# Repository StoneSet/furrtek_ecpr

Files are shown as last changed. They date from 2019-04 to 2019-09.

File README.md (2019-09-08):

# EPAR EMITTER HACK

## The Eagle project of the epar project + and modified firmware

**(c) Found the entire project here : http://furrtek.free.fr/?a=epar**

## For futher

As we know, only 350 cities (minimum), have been equipped with this system, (which makes 10% of the total cities in France in 2014). To have this famous cities code which is coded on 8 bits (so 255 possibilities), it is necessary to scan the frequencies 31MHz to 32MHz, which is tedious, this repo proposes to you a "brut-force", the program has been modified so that the 255 possibilities are tested. Once you have the code you can directly inform it in the remote control, it will go faster. This is just the theory, I have not tried it yet, but I would update this readme as soon as I have some pretty big breakthroughs.

## Included:

- All needed files to modify the project
- BOM (see in /pcb/)
- 🚧 Modified firmware (see in /firmware/) in WIP

## To use it :

1. Buy the pcb then solder every composants.
2. Flash the Atmega8 with *eparremote.hex* with these fuses :

- Low: *0xE4*, High: *0xD9*
## Some img's :

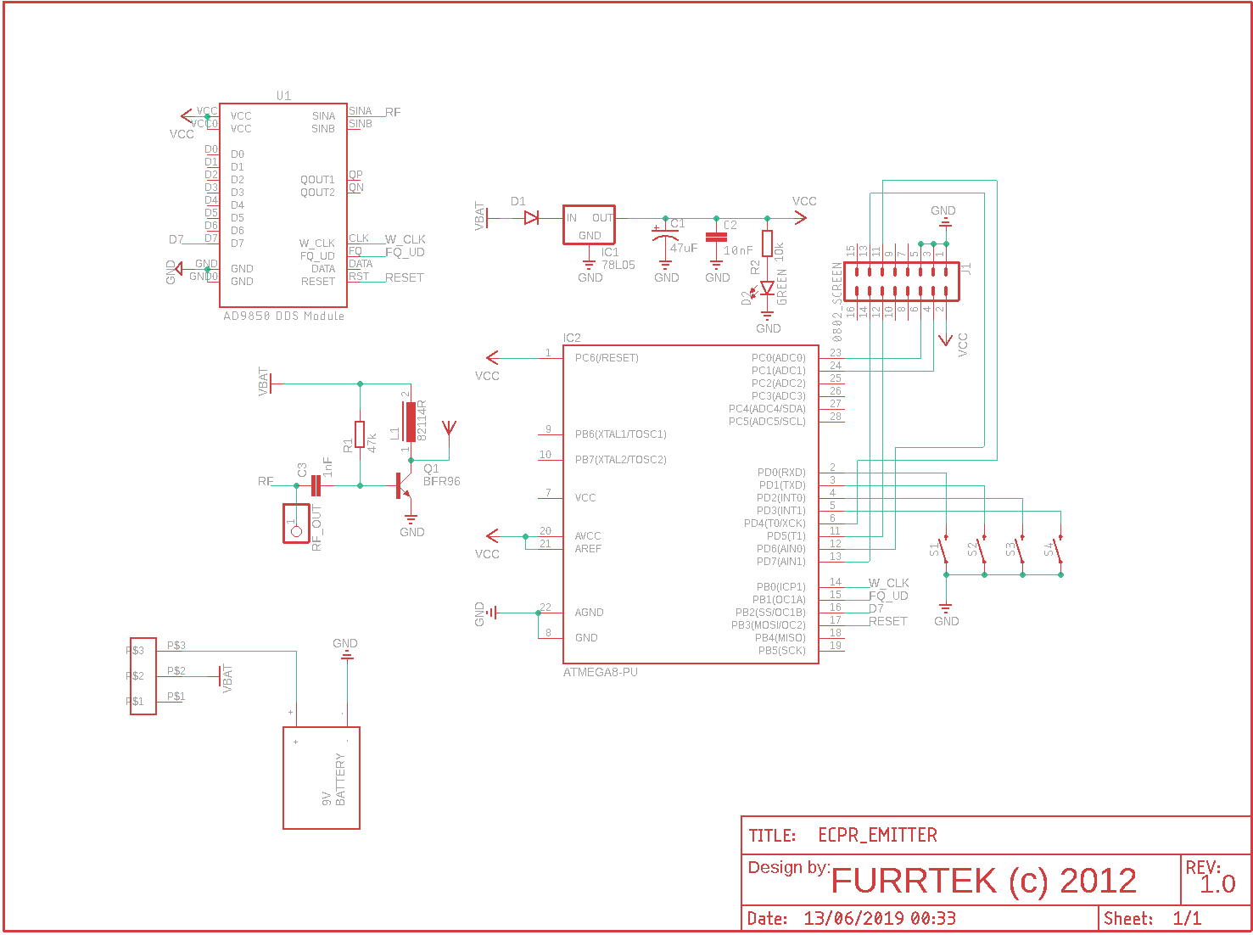
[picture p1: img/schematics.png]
schematic
remote 

gif_sdr#

### To dot it, you will need :

| Components | list |
|--|--|
| x1 Atmega8 | x1 78L05 regulator |
| x1 10k potentiometer | x4 12mm switch |
| x1 0802 screen | x1 AD9850 |
| x1 10k resistor | x1 47uF capacitor |
| x1 100uH coil | x1 Green led |
| x1 1nF capacitor | x1 10nF capacitor |
| x1 BFR96 | x1 47k resistor |
| x1 SPDT switch | x1 FM antenna |
| x1 9v clip | x1 1N4001 diode |

Tested, it will work perfectly !

#

(c) @furrtek & @StoneSet & @lefuturiste - http://furrtek.free.fr/?a=esl - http://stoneset.github.io/ (2019)

plz do not steal, i'm not the owner of this project, i'm only the owner of this pcb. Have fun !

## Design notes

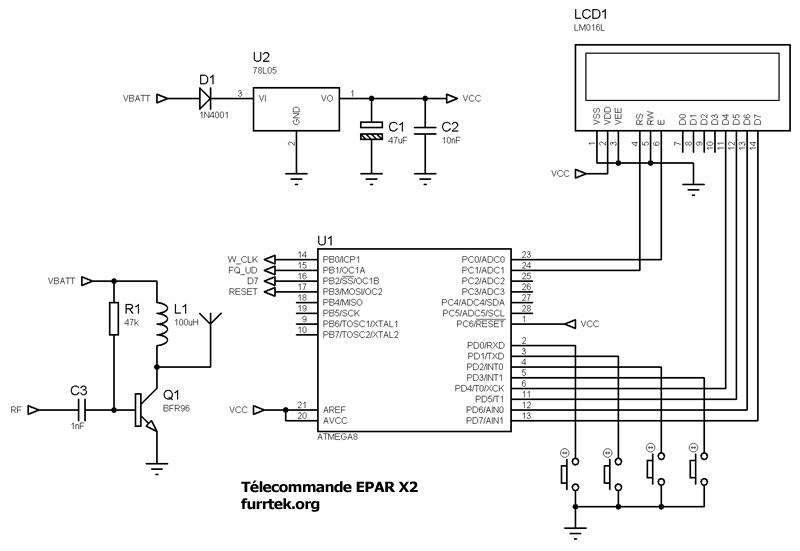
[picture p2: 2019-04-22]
img/schematics_furrtek.png

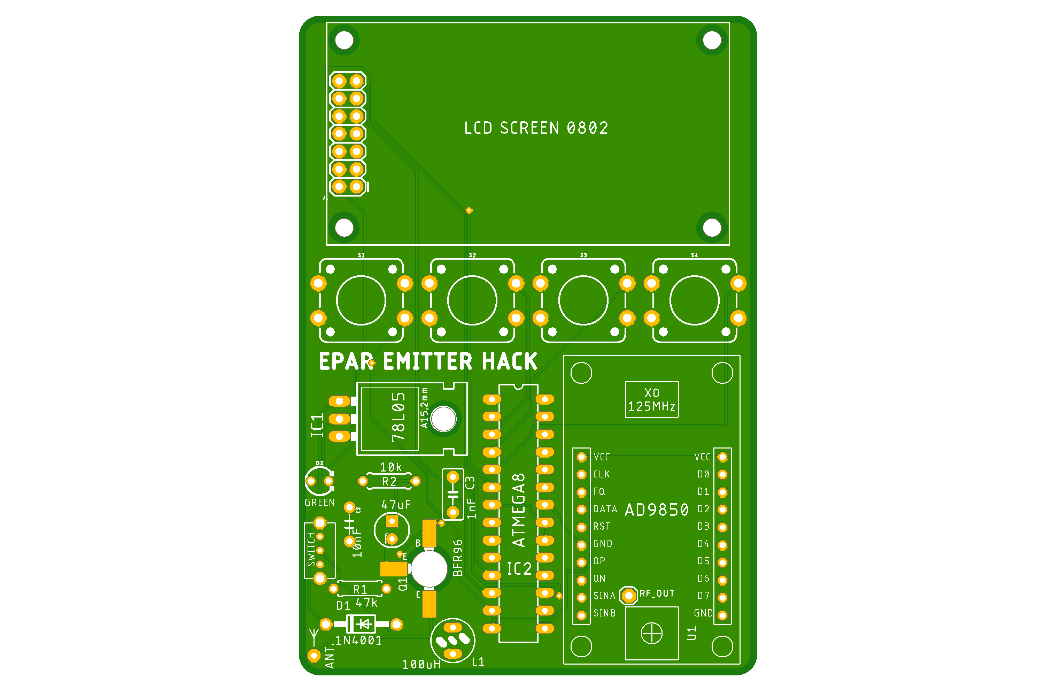
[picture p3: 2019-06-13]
img/board_top.png

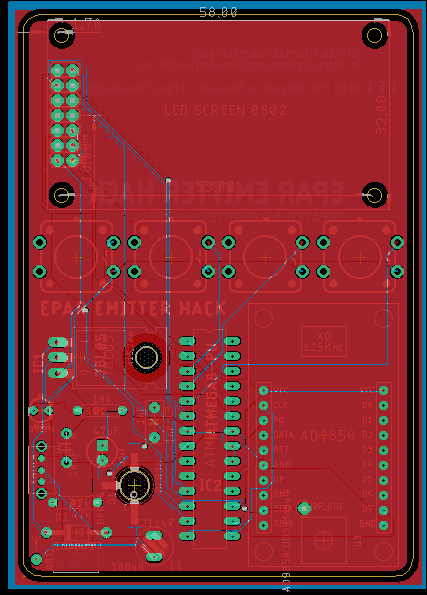
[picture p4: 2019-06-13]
img/board.png

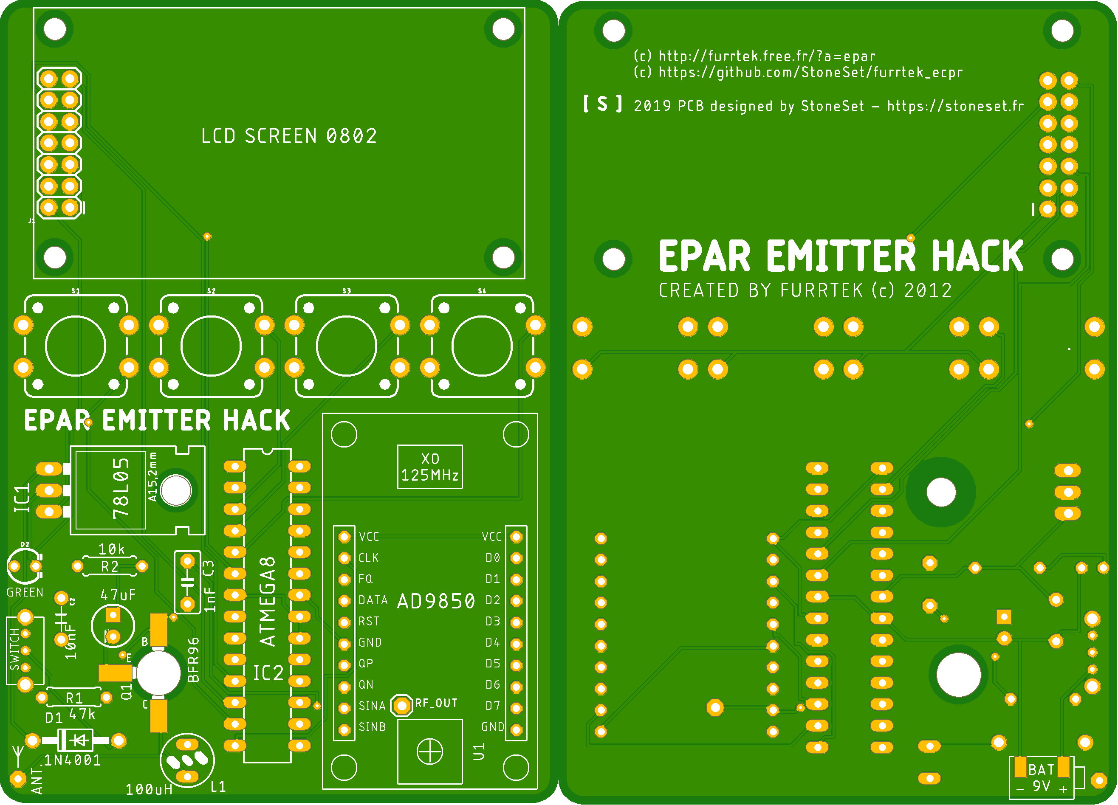
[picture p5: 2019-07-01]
img/top_bot.png

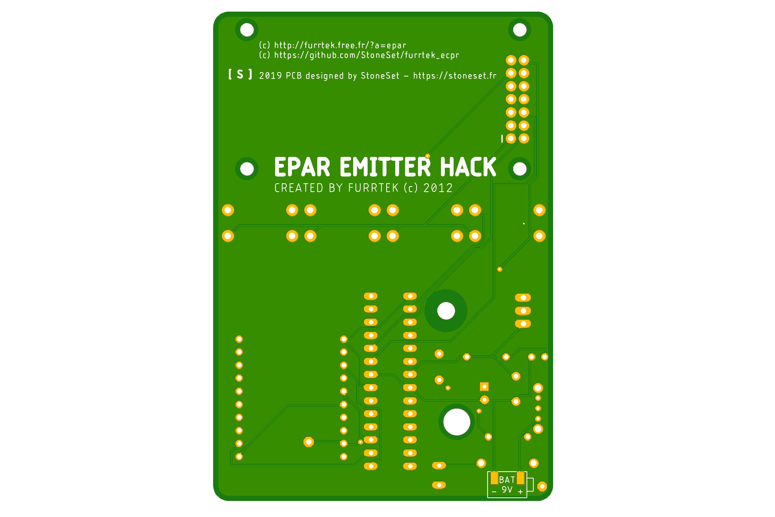
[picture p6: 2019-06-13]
img/board_bot.png

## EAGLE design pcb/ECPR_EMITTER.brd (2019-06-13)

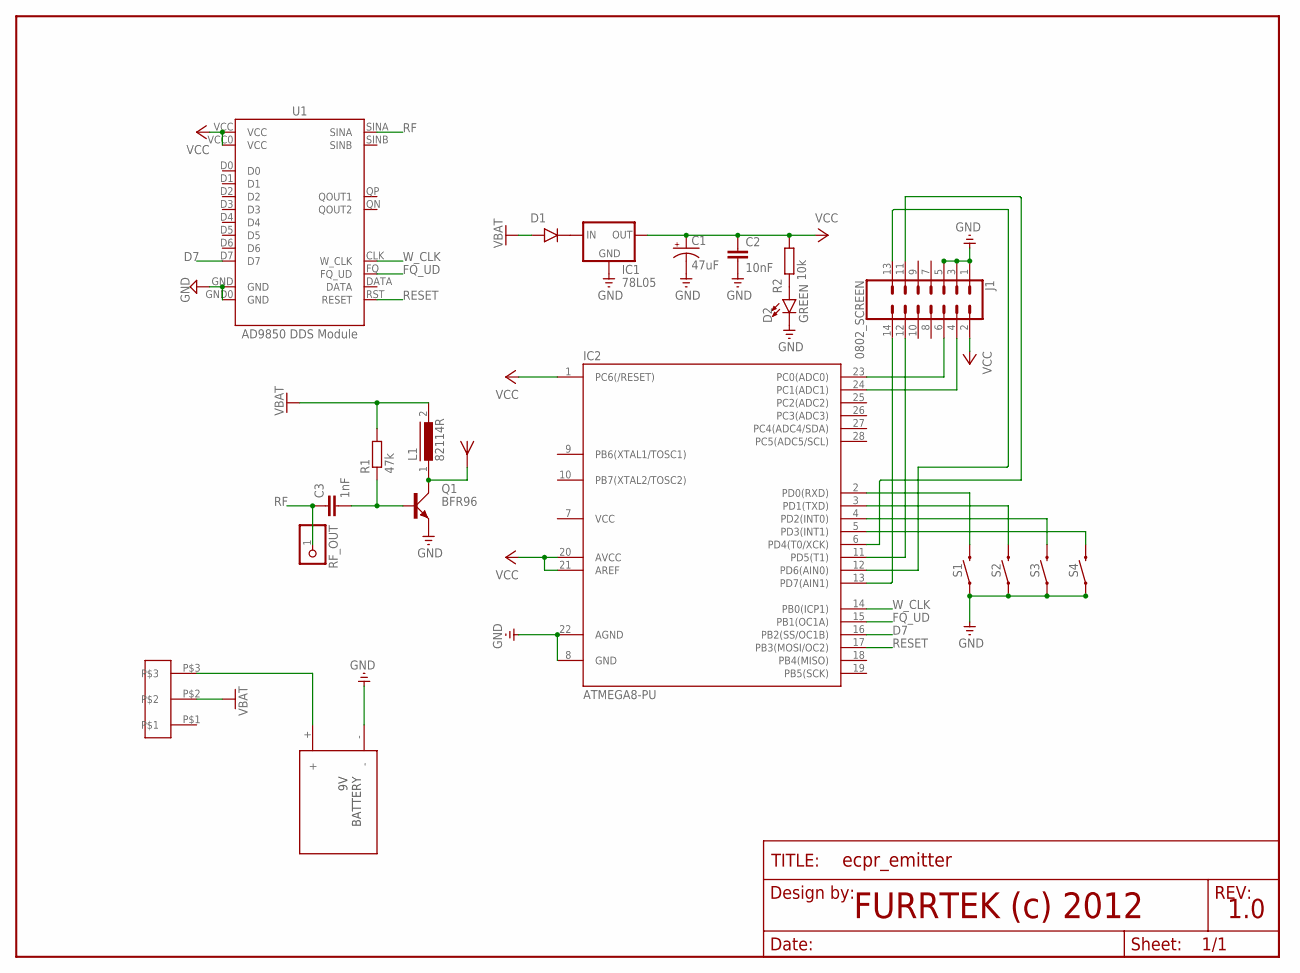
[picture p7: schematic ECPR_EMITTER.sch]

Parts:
C1: 47uF; CPOL-RADIAL-10UF-25V
C2: 10nF; CAP-PTH-10MM
C3: 1nF; C5B3
D1: 1N4001; DO41-10
D2: GREEN; LED_3MM-NS
FRAME1: FRAME-LETTERNO_PACKAGE; DUMMY
IC1: 78L05; 78XXL
IC2: ATMEGA8-PU; DIL28-3
J1: 0802_SCREEN; 2X8
L1: 82114R
Q1: BFR96; SOT37
R1: 47k; 0207/7
R2: 10k; 0207/7
RF_OUT: PINHD-1X1; 1X01
S1, S2, S3, S4: MOMENTARY-SWITCH-SPST-PTH-12MM; TACTILE_SWITCH_PTH_12MM
U1: AD9850 DDS Module; DDS_AD9850
U$1: ANT.; ANTENNA
U$2: PACKAGESWITCH; SLIDESWITCH
U$3: BAT

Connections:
D7: IC2.16 (PB2(SS/OC1B)), U1.D7
FQ_UD: IC2.15 (PB1(OC1A)), U1.FQ (FQ_UD)
GND: C1.2 (-), C2.2, D2.K (C), IC1.GND, IC2.8 (GND), IC2.22 (AGND), J1.1, J1.3, J1.5, Q1.2 (E), S1.1, S2.1, S3.1, S4.1, U1.GND, U1.GND0 (GND), U$3.-
unnamed: D1.C (CATHODE), IC1.IN
unnamed: C3.2, Q1.3 (B), R1.1
unnamed: IC2.2 (PD0(RXD)), S1.3 (2)
unnamed: IC2.3 (PD1(TXD)), S2.3 (2)
unnamed: IC2.4 (PD2(INT0)), S3.3 (2)
unnamed: IC2.5 (PD3(INT1)), S4.3 (2)
unnamed: L1.1, Q1.1 (C), U$1.ANT
unnamed: IC2.24 (PC1(ADC1)), J1.4
unnamed: IC2.23 (PC0(ADC0)), J1.6
unnamed: IC2.13 (PD7(AIN1)), J1.14
unnamed: IC2.11 (PD5(T1)), J1.12
unnamed: U$2.P$3, U$3.+
unnamed: IC2.12 (PD6(AIN0)), J1.13
unnamed: IC2.6 (PD4(T0/XCK)), J1.11
unnamed: D2.A, R2.1
RESET: IC2.17 (PB3(MOSI/OC2)), U1.RST (RESET)
RF: C3.1, RF_OUT.1, U1.SINA
VBAT: D1.A (ANODE), L1.2, R1.2, U$2.P$2
VCC: C1.1 (+), C2.1, IC1.OUT, IC2.1 (PC6(/RESET)), IC2.7 (VCC), IC2.20 (AVCC), IC2.21 (AREF), J1.2, R2.2, U1.VCC, U1.VCC0 (VCC)
W_CLK: IC2.14 (PB0(ICP1)), U1.CLK (W_CLK)

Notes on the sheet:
FURRTEK (c) 2012
1.0

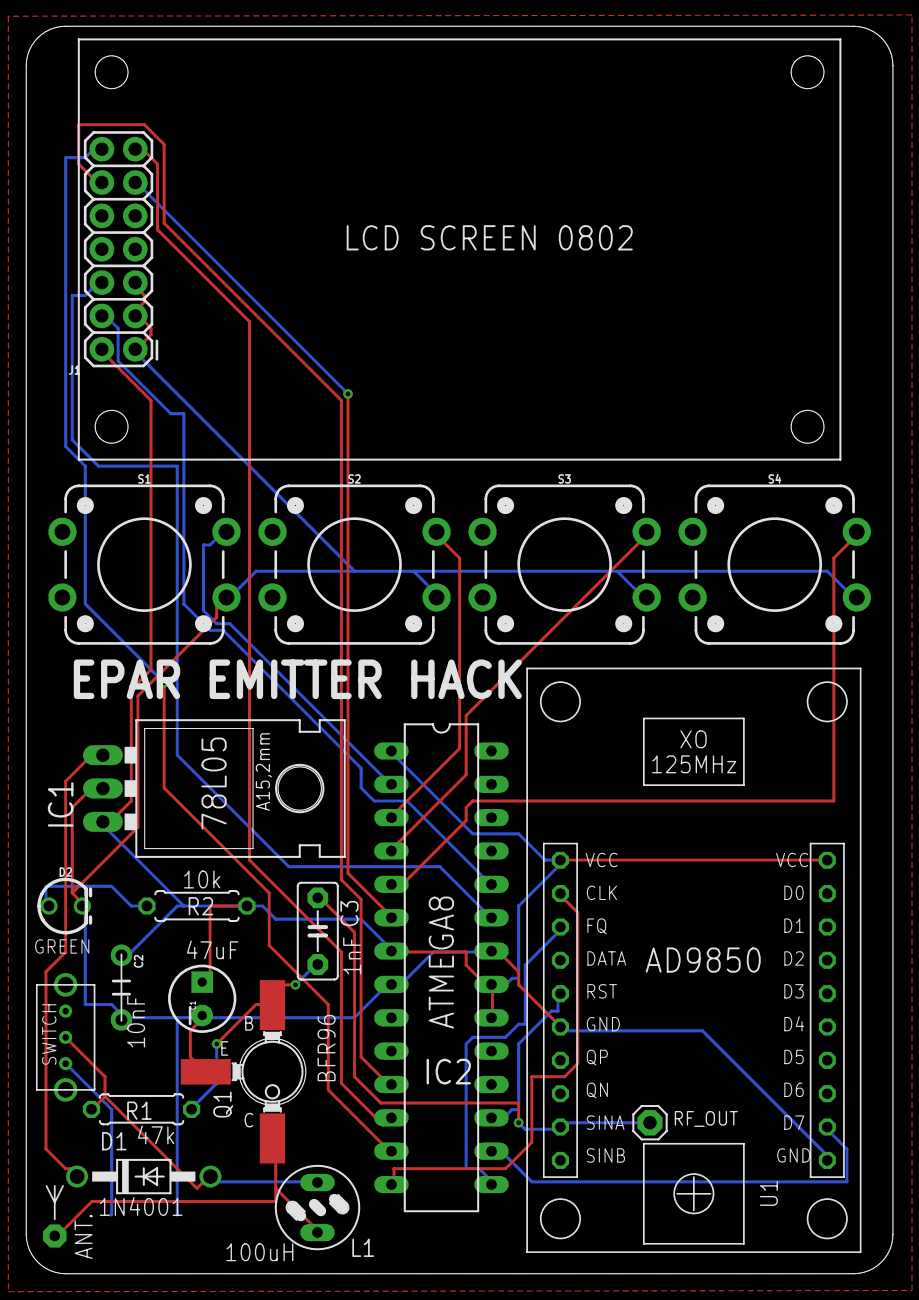
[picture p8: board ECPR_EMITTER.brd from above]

Board: 2 copper layers, 66.0 x 95.0 mm, 22 parts (1 on the bottom side), 23 nets.

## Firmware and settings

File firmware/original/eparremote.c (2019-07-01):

/*
Telecommande EPAR v1.1
07/10/2012 CC by Furrtek
ATMega8 8Mhz RC
*/

#define F_CPU 8000000UL

#include <avr/io.h>
#include <avr/interrupt.h>
#include <util/delay.h>
#include <stdlib.h>
#include <inttypes.h>
#include <avr/pgmspace.h>
#include <avr/eeprom.h>

#include "special.h"
#include "lcd.h"
#include "eparremote.h"
#include "navig.h"

typedef void (*FuncPtr)();
FuncPtr FPtr;

uint8_t editing=0;		// Bool valeur en edition
uint8_t selected=0;		// Bool chiffre choisi
uint8_t reli=0;			// # relais en edition
uint8_t bitedit=0;		// # bit en edition
uint8_t digitedit=0;	// # chiffre en edition

uint8_t relay[2] = {0,0};	// Etat relais
uint8_t menu = MENU_CODE;	// Menu (au demarrage)
double fr;					// Valeur frequence centrale (MHz)
double ec;					// Valeur ecart frequence (MHz)
uint8_t citycode;
uint8_t zone;

uint8_t EEMEM EEcode;		// Sauvegardes en EEPROM
uint8_t EEMEM EEzone;
uint8_t EEMEM EEmenu;
uint32_t EEMEM EEfr;
uint32_t EEMEM EEec;

const uint8_t fwa[] PROGMEM = "TLC EPAR";	// Splash pour se la peter
const uint8_t fwb[] PROGMEM = "Ver. 1.1";
const uint8_t fwc[] PROGMEM = "Furrtek\"";
const uint8_t fwd[] PROGMEM = "07/10/12";

// Table de handlers pour les menus
const FuncPtr FTableEditing[] PROGMEM = {FE_DIGIT,FE_DIGIT,FE_REL,FE_CODE,FE_ZONE,FE_XMIT};
const FuncPtr FTableChoose[] PROGMEM = {FC_FREQ,FC_SPAN,FC_REL,FC_CODE,FC_ZONE,FC_XMIT};
const FuncPtr FTableLeftEditing[] PROGMEM = {FLE_FREQ,FLE_SPAN,FLE_REL,FLE_CODE,FLE_ZONE,FLE_XMIT};
const FuncPtr FTableRightEditing[] PROGMEM = {FRE_FREQ,FRE_SPAN,FRE_REL,FRE_CODE,FRE_ZONE,FRE_XMIT};
const FuncPtr FTableDisp[] PROGMEM = {FD_FREQ,FD_SPAN,FD_REL,FD_CODE,FD_ZONE,FD_XMIT};
const FuncPtr FTableSave[] PROGMEM = {FS_FREQ,FS_SPAN,FS_REL,FS_CODE,FS_ZONE,FS_XMIT};

const double power[6] = {0.0001,0.001,0.01,0.1,1,10};	// Puissances de 10

void disp() {
	// MAJ affichage LCD
	FPtr=(FuncPtr)pgm_read_word(&FTableDisp[menu]);
	FPtr();
}

int main(void) {
	WDTCR = (1<<WDCE) | (1<<WDE);	// Watchdog off (dangereux)
	WDTCR = 0x00;

	DDRB = 0b00001111;	// Outputs vers AD9850
	DDRD = 0b11110000;	// Data LCD
	DDRC = 0b00000011;	// Control LCD

	PORTD = 0b00100000 | PULLUPS;	// Mode 8 bits
	_delay_us(100);
	PORTC |= _BV(E);
	_delay_us(100);
	PORTC &= ~_BV(E);
	_delay_us(100);

	com(0b00101000);		// 2 lignes
	com(0b00000001);		// Clear
	com(0b00000010);		// Home
	com(0b00001100);		// Ecran on, cursor off, blink off

	com(0b10000000);		// Ligne 1
	wrt(fwa);
	com(0b11000000);		// Ligne 2
	wrt(fwb);

	_delay_ms(1000);

	com(0b10000000);		// Ligne 1
	wrt(fwc);
	com(0b11000000);		// Ligne 2
	wrt(fwd);

	_delay_ms(1000);

	PORTB = _BV(AD9850_RESET);	// Init mode serie AD9850
	_delay_ms(100);
	PORTB = 0;
	_delay_ms(100);

	PORTB = _BV(AD9850_W_CLK);
	_delay_ms(1);
	PORTB = 0;
	_delay_ms(1);

	PORTB = _BV(AD9850_FQ_UD);
	_delay_ms(1);
	PORTB = 0;
	_delay_ms(1);

	update(0,POWERDOWN);	// DDS au dodo

	// Recup sauvegarde EEPROM + sanitizing
	//menu = eeprom_read_byte(&EEmenu);
	//if (menu > MENU_LAST) menu = MENU_FIRST;
	citycode = eeprom_read_byte(&EEcode);
	zone = eeprom_read_byte(&EEzone);
	if (zone > 3) zone = 3;

	eeprom_read_block((void*)&ec, (const void*)&EEec, sizeof(double));
	if ((((*(uint32_t*)&ec) & 0x7fffffff) > 0x7f800000)||(ec < ECART_MIN)||(ec > ECART_MAX)) ec = 0.003;
	eeprom_read_block((void*)&fr, (const void*)&EEfr, sizeof(double)); 
	if ((((*(uint32_t*)&fr) & 0x7fffffff) > 0x7f800000)||(fr < FREQ_MIN)||(fr > FREQ_MAX)) fr = 31;

	disp();

	for (;;) {
		while ((PIND & PULLUPS) == PULLUPS) {};
		_delay_ms(50);
		if (!bit_is_set(PIND,PD0)) {
			// Gauche
			while(!bit_is_set(PIND,PD0)) {};
			if (editing) {
				// Modif valeur
				FPtr=(FuncPtr)pgm_read_word(&FTableLeftEditing[menu]);
				FPtr();
			} else {
				// Menu precedent
				if (menu == MENU_FIRST) {
					menu = MENU_LAST;
				} else {
					menu--;
				}
				disp();
			}
		} else if (!bit_is_set(PIND,PD3)) {
			// Droite
			while(!bit_is_set(PIND,PD3)) {};
			if (editing) {
				// Modif valeur
				FPtr=(FuncPtr)pgm_read_word(&FTableRightEditing[menu]);
				FPtr();
			} else {
				// Menu suivant
				if (menu == MENU_LAST) {
					menu = MENU_FIRST;
				} else {
					menu++;
				}
				disp();
			}
		} else if (!bit_is_set(PIND,PD1)) {
			// Edition
			while(!bit_is_set(PIND,PD1)) {};
			if (editing) {
				// Modif valeur
				FPtr=(FuncPtr)pgm_read_word(&FTableEditing[menu]);
				FPtr();
			} else {
				// Selection valeur
				eeprom_write_byte(&EEmenu,menu);
				editing = 1;
				digitedit = 0;
				FPtr=(FuncPtr)pgm_read_word(&FTableChoose[menu]);
				FPtr();
			}
		} else if (!bit_is_set(PIND,PD2)) {
			// Validation
			while(!bit_is_set(PIND,PD2)) {};
			editing = 0;
			selected = 0;
			com(0b00001100);		// blink et cursor off
			FPtr=(FuncPtr)pgm_read_word(&FTableSave[menu]);
			FPtr();
		}
	}

  return 0;
}

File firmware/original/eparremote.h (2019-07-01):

#define PULLUPS 0b00001111

void com(uint8_t command);
void disp();
void cur_rel();
void cur_freq();
void cur_span();
void cur_code();
void cur_zone();
void wrt(const uint8_t *FlashLoc);
void EPAR_TX(uint8_t citycode, uint8_t zone, uint8_t relay, uint8_t state, uint8_t reverse, uint8_t rep);
void wrtr(char *cbuf);
void wrtc(char chr);
void Up();
void Down();
uint8_t hex(uint8_t num);

#define ZONE_A 0
#define ZONE_B 1
#define ZONE_C 2
#define ZONE_TP 3

#define RELAY1	1
#define RELAY2  0

#define OPEN 0
#define CLOSED 1

#define NORMAL 0
#define REVERSE 1

#define REPEAT 26

#define FREQ_MAX 40
#define FREQ_MIN 20

#define ECART_MAX 1
#define ECART_MIN 0.001

#define POWERDOWN 4

#define AD9850_W_CLK	PB0
#define AD9850_FQ_UD	PB1
#define AD9850_D7		PB2
#define AD9850_RESET	PB3

#define E	PC0
#define RS	PC1

enum MENUT {MENU_FREQ,MENU_SPAN,MENU_REL,MENU_CODE,MENU_ZONE,MENU_XMIT};

#define MENU_FIRST MENU_FREQ
#define MENU_LAST MENU_XMIT

const double power[6];

char test[8];

uint8_t editing,selected;
uint8_t reli,bitedit,digitedit;

uint8_t relay[2],menu;
double	fr;
uint8_t citycode;
uint8_t zone;
double ec;

uint8_t EEcode;
uint8_t EEzone;
uint8_t EEmenu;
uint32_t EEfr;
uint32_t EEec;

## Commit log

2017-09-06 First release (Yay!)
    yay
    [Epar PCB.fzz]
2019-04-22 feat(pcb): add eagle project w/ :
    - BOM
    - img
    - zip of furrtek website
    - all libs
    - gerber
    [ECPR_EMITTER.brd, ECPR_EMITTER.sch, Epar PCB.fzz]
2019-04-22 feat(board): final version w/ led, switch, pads for battery, rf connected, new version of AD9850 libs
    [ECPR_EMITTER.brd, ECPR_EMITTER.sch]
2019-04-23 feat(button): move button to the top
    [ECPR_EMITTER.brd]
2019-04-24 feat(testpin): add rf out and update to eagle 9.4.0
    [ECPR_EMITTER.brd, ECPR_EMITTER.sch]
2019-04-24 feat(pcb): add rounded corners to the pcb
    [ECPR_EMITTER.brd]
2019-06-12 fix: screen orientation & pin23/24
    [ECPR_EMITTER.brd, ECPR_EMITTER.sch]
2019-07-01 WIP feat: modified firmware (nothing at this time, but u should wait)
    be patient
2019-08-07 feat(refactor): big refactoring & new readme
    modified firmware in WIP
    [ECPR_EMITTER.brd, ECPR_EMITTER.sch]

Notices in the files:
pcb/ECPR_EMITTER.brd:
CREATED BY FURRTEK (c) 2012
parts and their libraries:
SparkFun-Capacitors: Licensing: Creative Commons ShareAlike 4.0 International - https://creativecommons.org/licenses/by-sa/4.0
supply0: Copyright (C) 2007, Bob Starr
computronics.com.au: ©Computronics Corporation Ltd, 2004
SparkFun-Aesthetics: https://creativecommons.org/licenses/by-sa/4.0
